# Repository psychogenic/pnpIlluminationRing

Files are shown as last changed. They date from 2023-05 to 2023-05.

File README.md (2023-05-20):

# PnP Illumination Ring
Open source hardware illumination ring project, for Charmhigh T36VA pick and place or others.

It's a simple little LED ring that has made a big impact on the reliability of the pick and place machine, 
and I've used it with a number of differently sized fiducials under various lighting conditions to great
success.

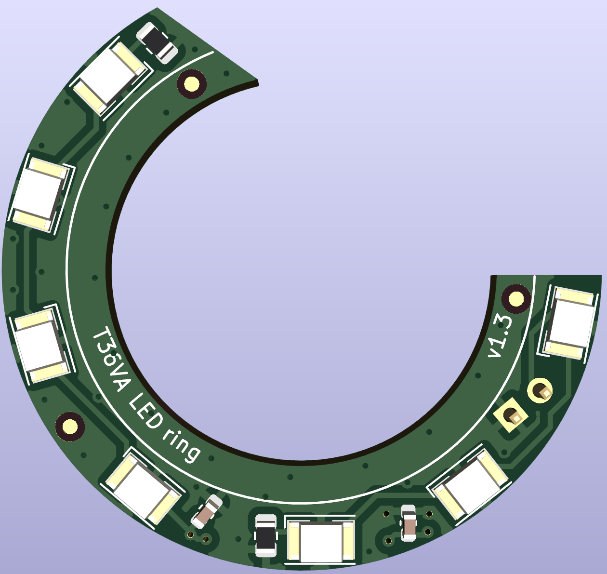
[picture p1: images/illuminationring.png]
LED Ring


I've detailed the project and demoed its function [on youtube](https://youtu.be/Ot52M9ZeZmY).

The project is released under the CERN OHL license, see LICENSE.txt for deets.
```
--------------------------------------------------------------------------------
| Copyright Pat Deegan 2023.                                                   |
|                                                                              |
| This is an Open Hardware project and is licensed under the CERN-OHL-S v2.    |
|                                                                              |
| You may redistribute and modify this source and make products using it under |
| the terms of the CERN-OHL-S v2 (https://ohwr.org/cern_ohl_s_v2.txt).         |
|                                                                              |
| This source is distributed WITHOUT ANY EXPRESS OR IMPLIED WARRANTY,          |
| INCLUDING OF MERCHANTABILITY, SATISFACTORY QUALITY AND FITNESS FOR A         |
| PARTICULAR PURPOSE. Please see the CERN-OHL-S v2 for applicable conditions.  |
|                                                                              |
| Source location: https://github.com/psychogenic/pnpIlluminationRing          |
|                                                                              |
| As per CERN-OHL-S v2 section 4, should You produce hardware based on this    |
| source, You must where practicable maintain the Source Location visible      |
| on the external case of the Gizmo or other products you make using this      |
| source.                                                                      |
--------------------------------------------------------------------------------
```

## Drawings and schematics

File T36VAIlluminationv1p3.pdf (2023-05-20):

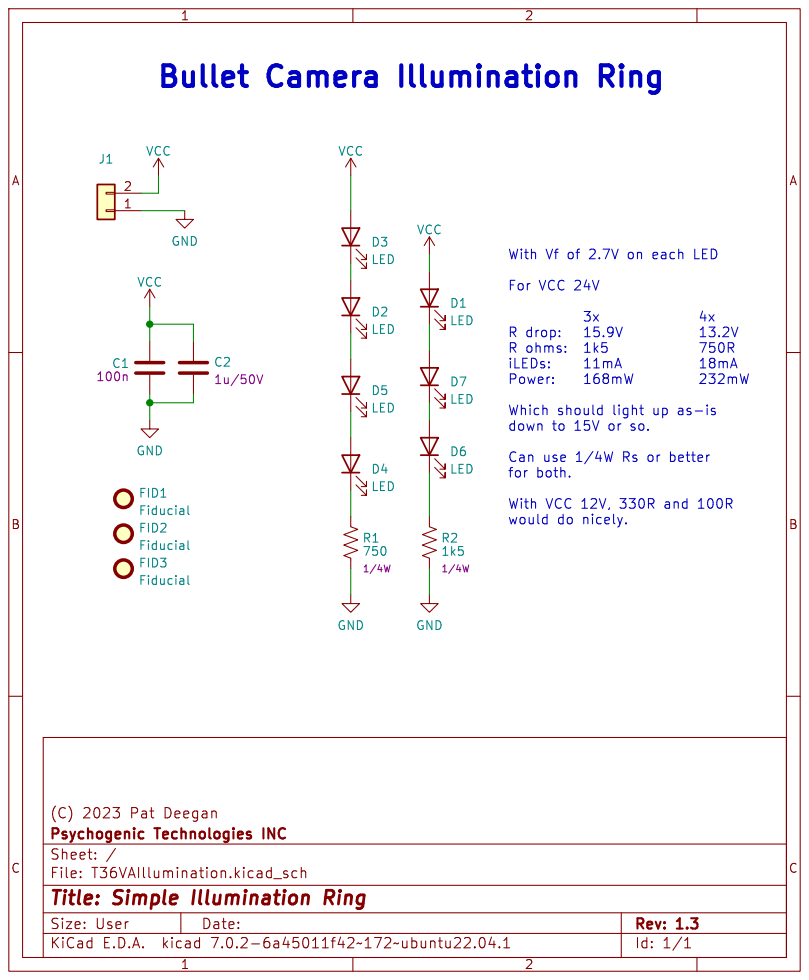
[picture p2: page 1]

With Vf of 2.7V on each LED

Which should light up as-is down to 15V or so. Can use 1/4W Rs or better

for both. With VCC 12V, 330R and 100R

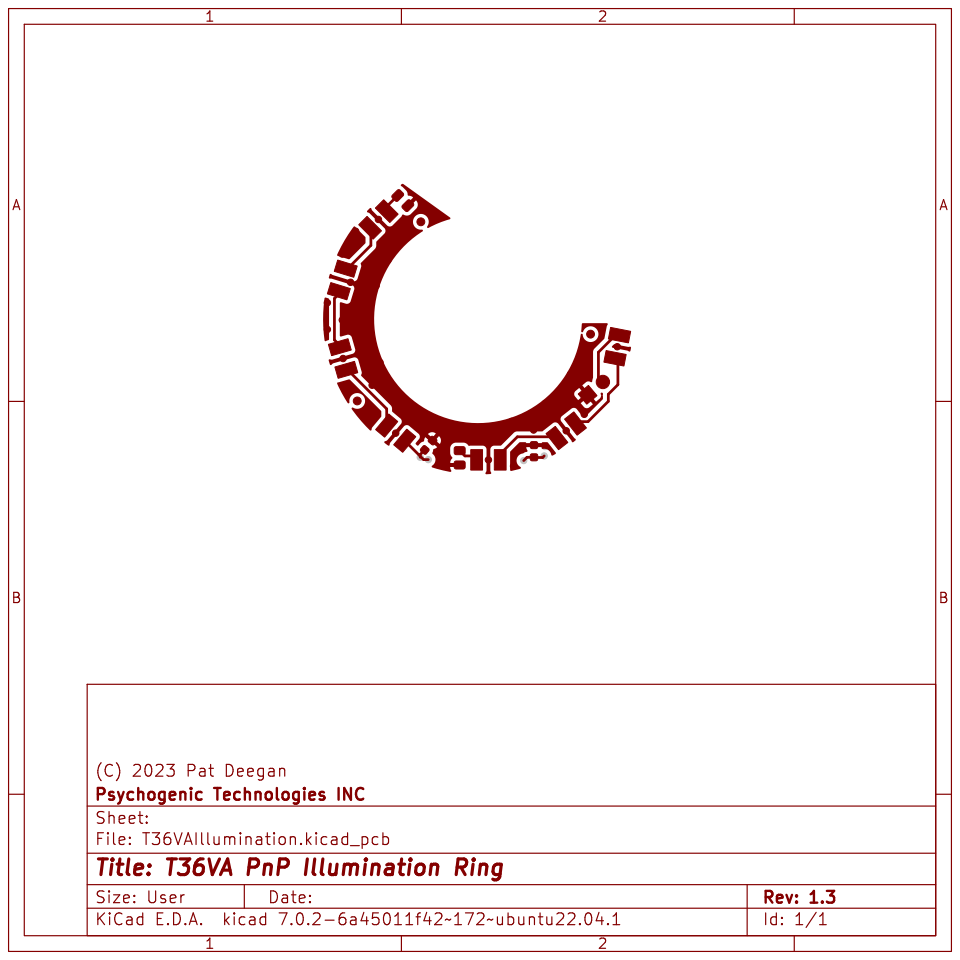
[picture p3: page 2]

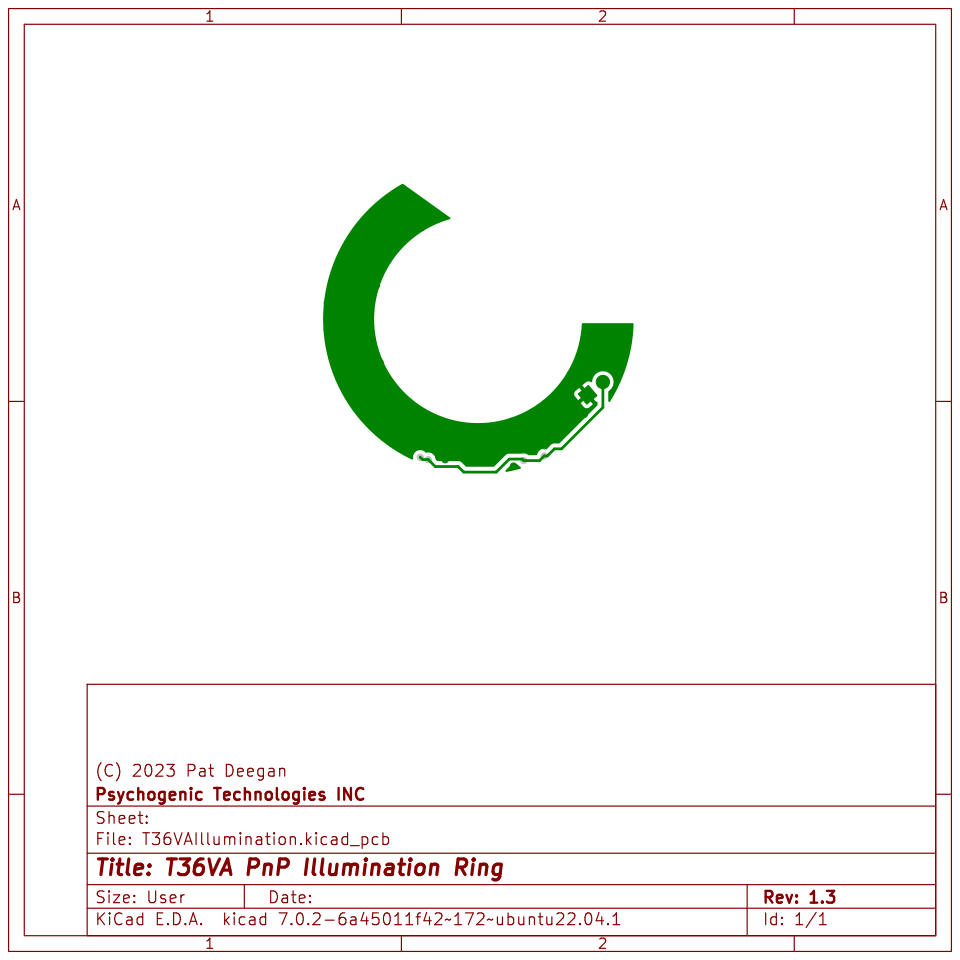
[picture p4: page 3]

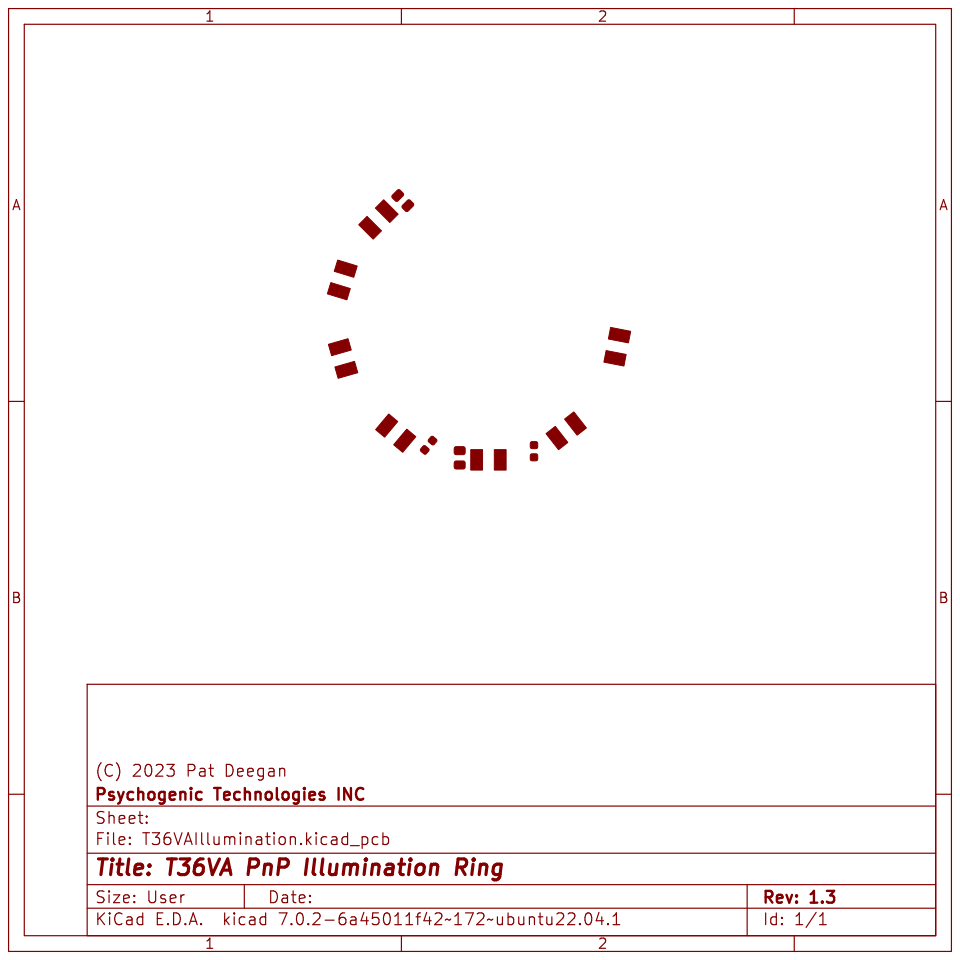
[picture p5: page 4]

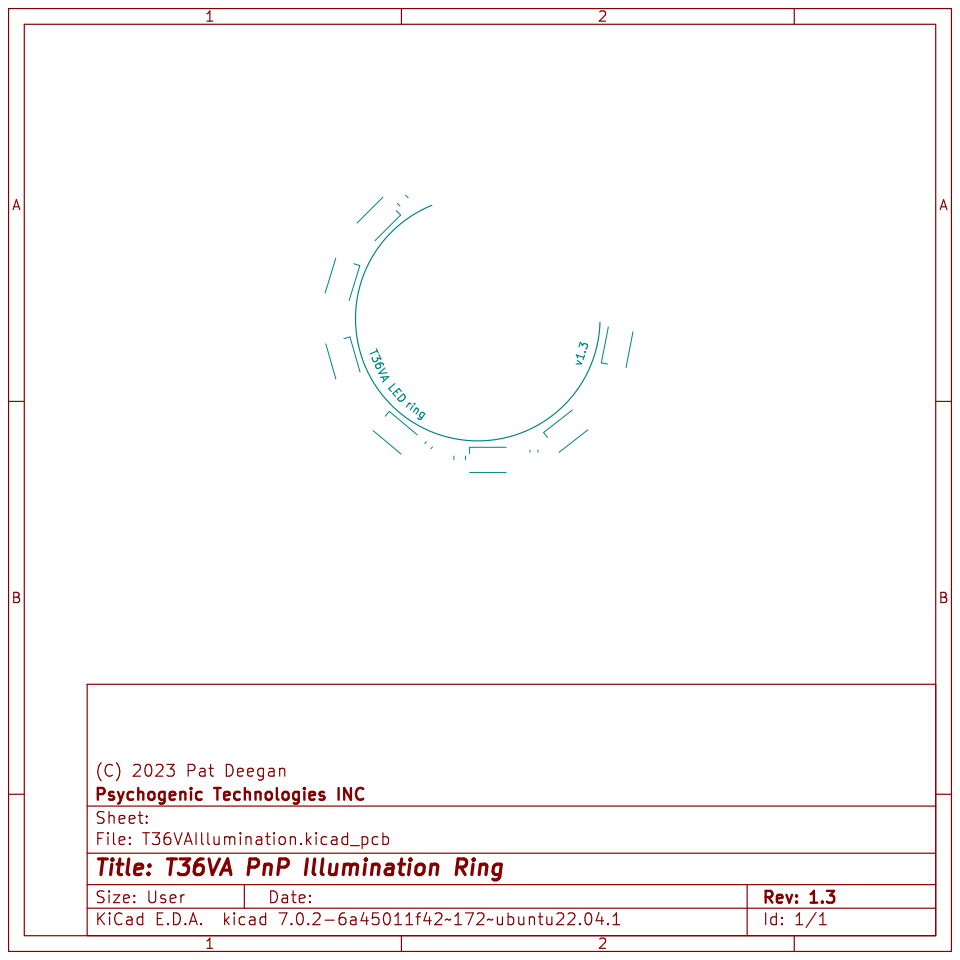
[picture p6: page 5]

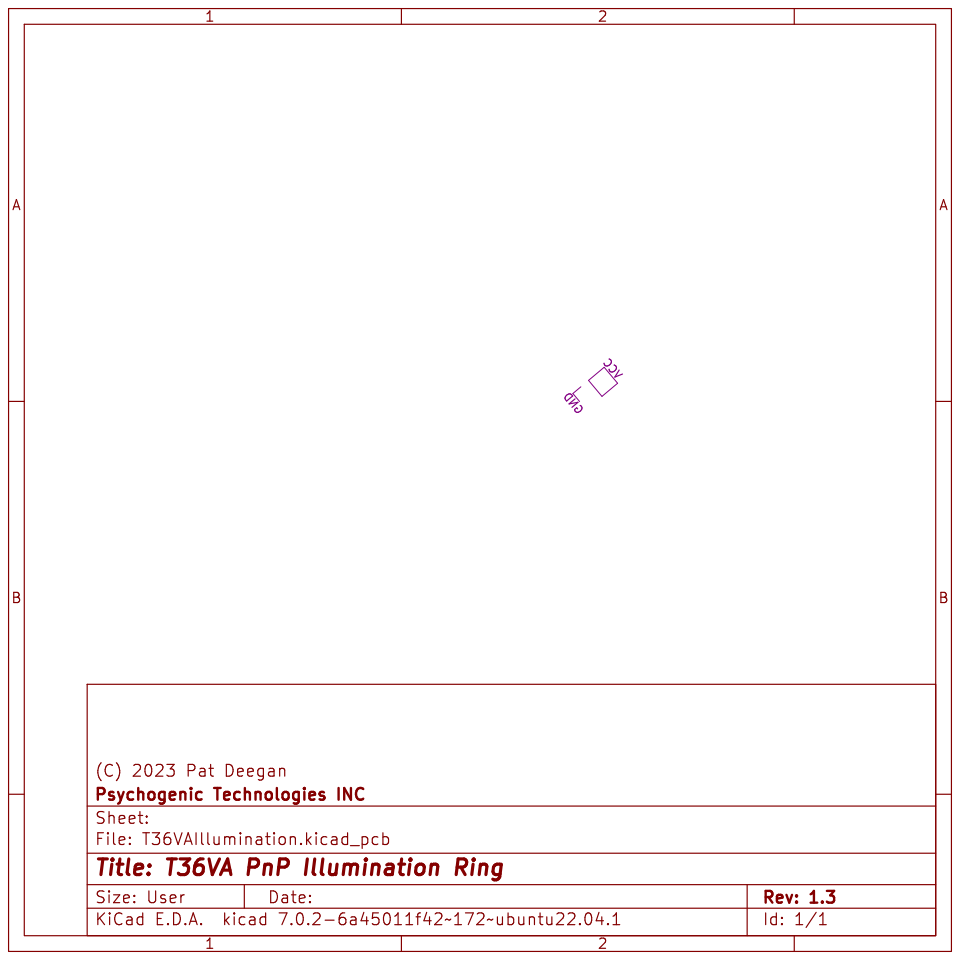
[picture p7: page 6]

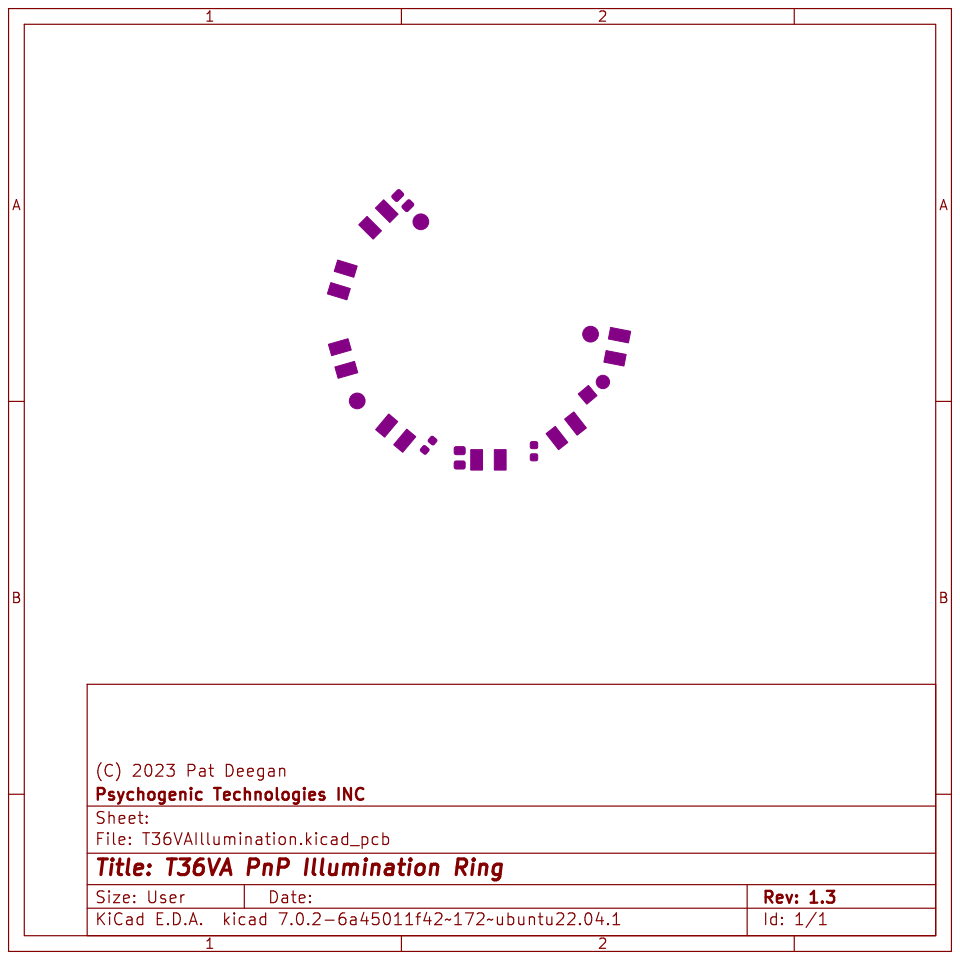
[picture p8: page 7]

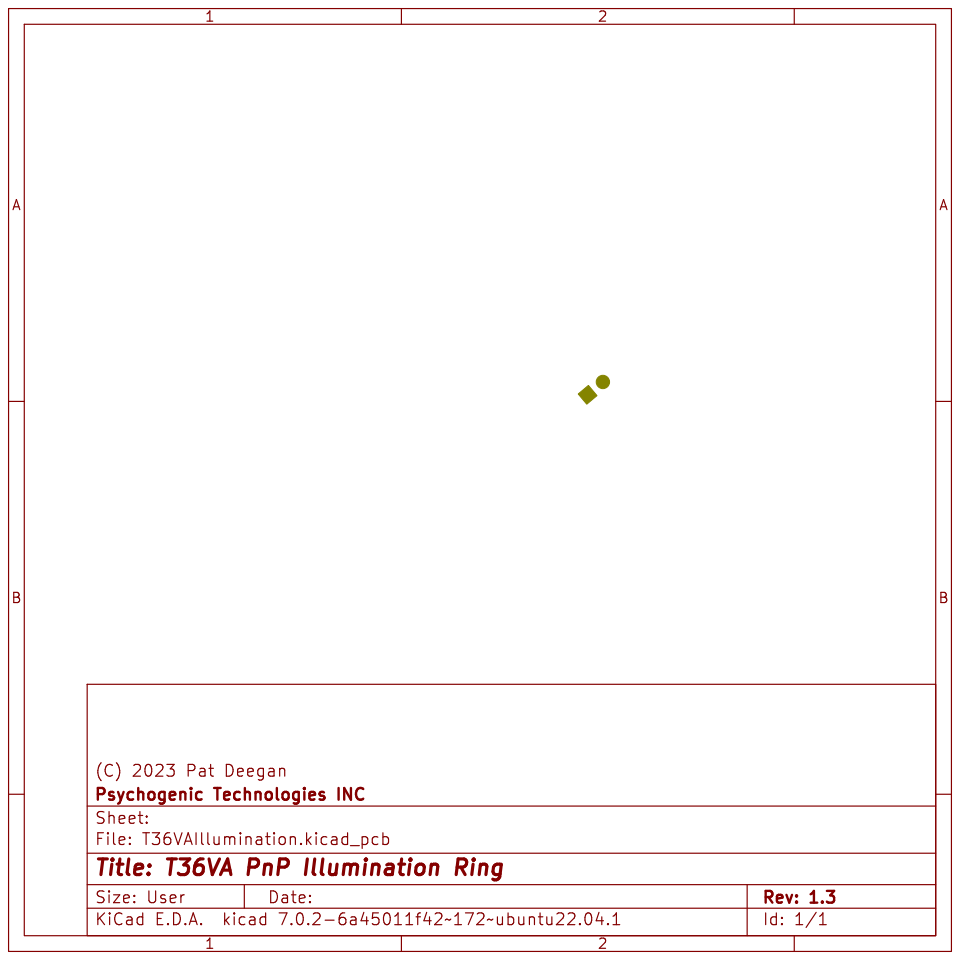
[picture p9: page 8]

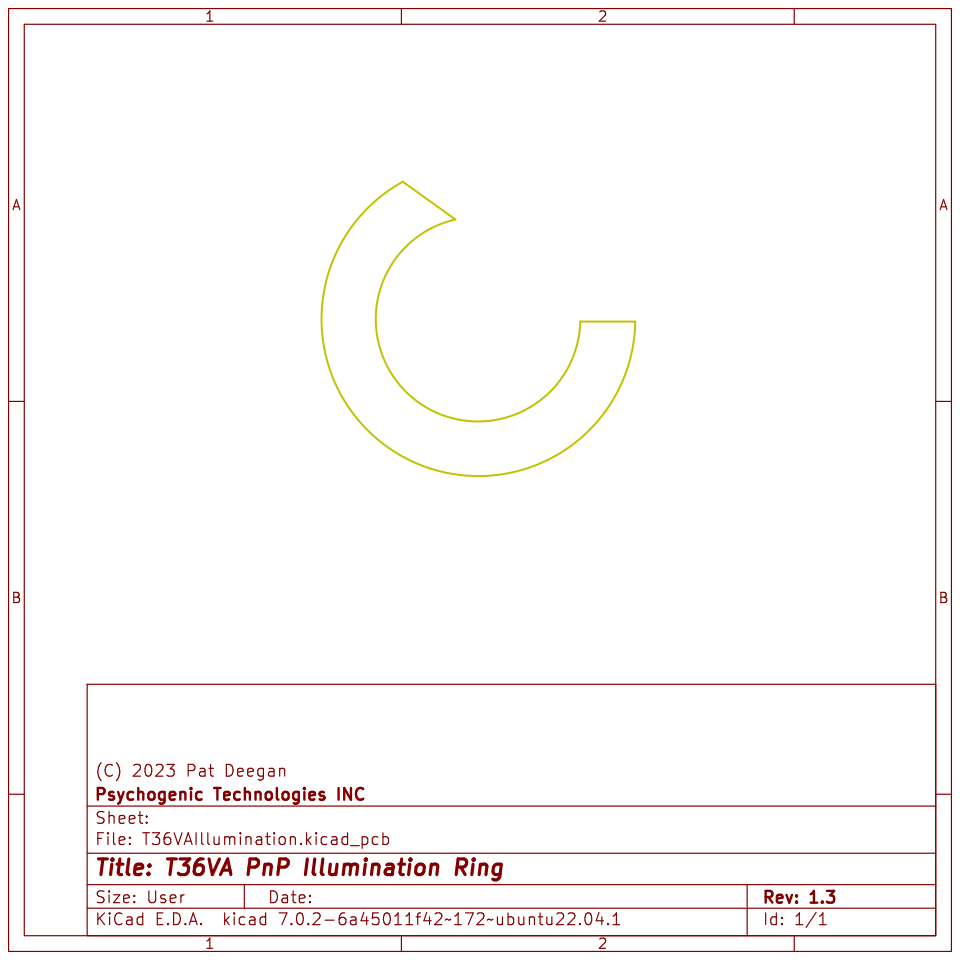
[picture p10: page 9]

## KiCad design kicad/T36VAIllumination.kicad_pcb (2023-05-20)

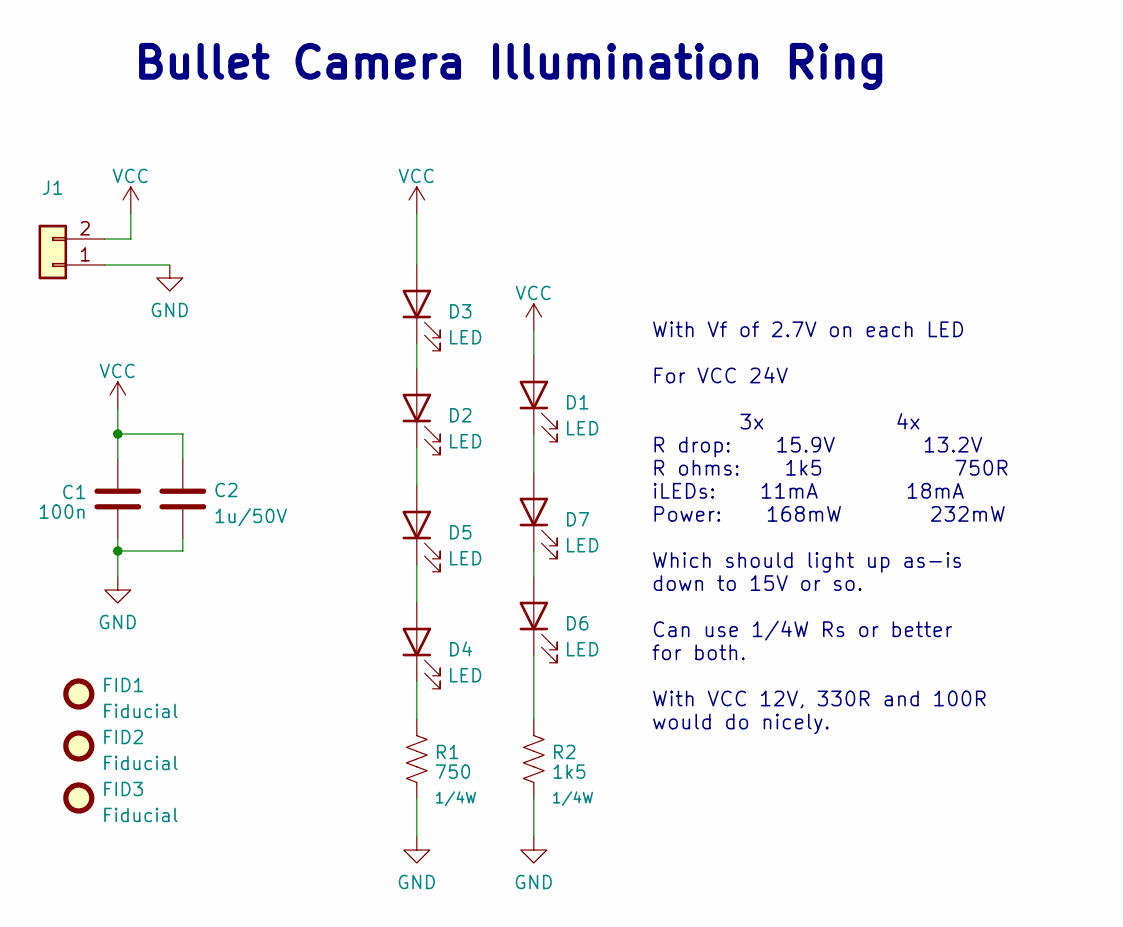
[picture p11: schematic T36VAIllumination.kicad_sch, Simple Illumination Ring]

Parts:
C1: C_100n_0603_50V; C_0603_1608Metric
C2: C_1u_0603_50V; C_0603_1608Metric
D1, D2, D3, D4, D5, D6, D7: LED; LED_PLCC-2
FID1, FID2, FID3: Fiducial; Fiducial_1mm_Mask2mm
J1: Conn_01x02; PinHeader_1x02_P2.54mm_Vertical
R1: 750; R_0805_2012Metric
R2: 1k5; R_0805_2012Metric

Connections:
GND: C1.2, C2.2, J1.1, R1.2, R2.2
unnamed: D1.1 (K), D7.2 (A)
unnamed: D2.1 (K), D5.2 (A)
unnamed: D2.2 (A), D3.1 (K)
unnamed: D4.1 (K), R1.1
unnamed: D4.2 (A), D5.1 (K)
unnamed: D6.1 (K), R2.1
unnamed: D6.2 (A), D7.1 (K)
VCC: C1.1, C2.1, D1.2 (A), D3.2 (A), J1.2

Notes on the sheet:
With Vf of 2.7V on each LED For VCC 24V 3x 4x R drop: 15.9V 13.2V R ohms: 1k5 750R iLEDs: 11mA 18mA Power: 168mW 232mW Which should light up as-is down to 15V or so. Can use 1/4W Rs or better for both. With VCC 12V, 330R and 100R would do nicely.
Bullet Camera Illumination Ring

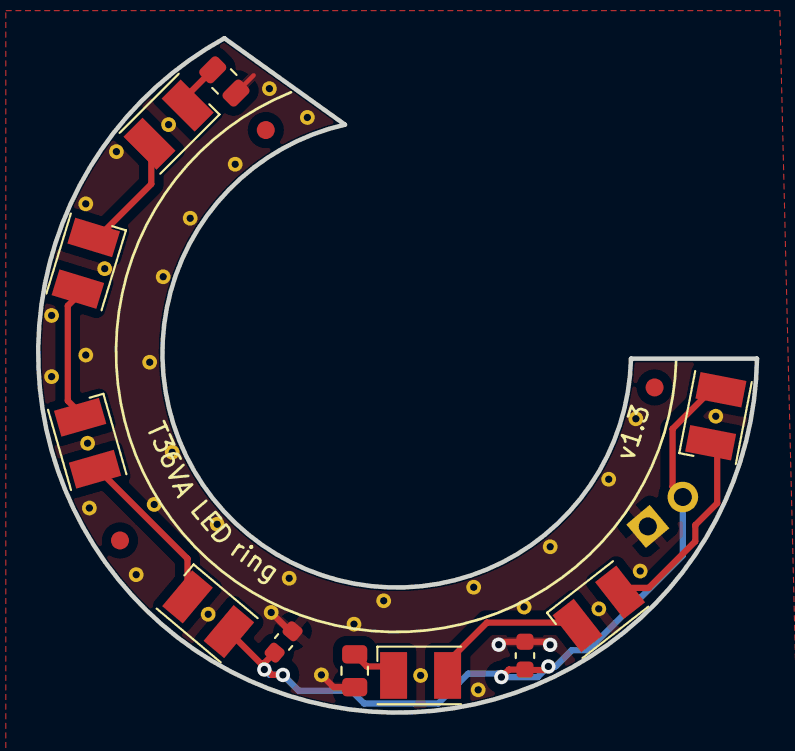
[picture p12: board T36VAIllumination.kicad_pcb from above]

Board: 2 copper layers, 39.9 x 37.5 mm, 15 parts (1 on the bottom side), 9 nets.

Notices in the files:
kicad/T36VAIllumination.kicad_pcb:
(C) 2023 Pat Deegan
